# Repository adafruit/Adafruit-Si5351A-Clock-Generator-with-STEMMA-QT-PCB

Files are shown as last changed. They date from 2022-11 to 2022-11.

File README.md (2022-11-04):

## Adafruit Adafruit Si5351A Clock Generator with STEMMA QT 8KHz to 160MHz PCB

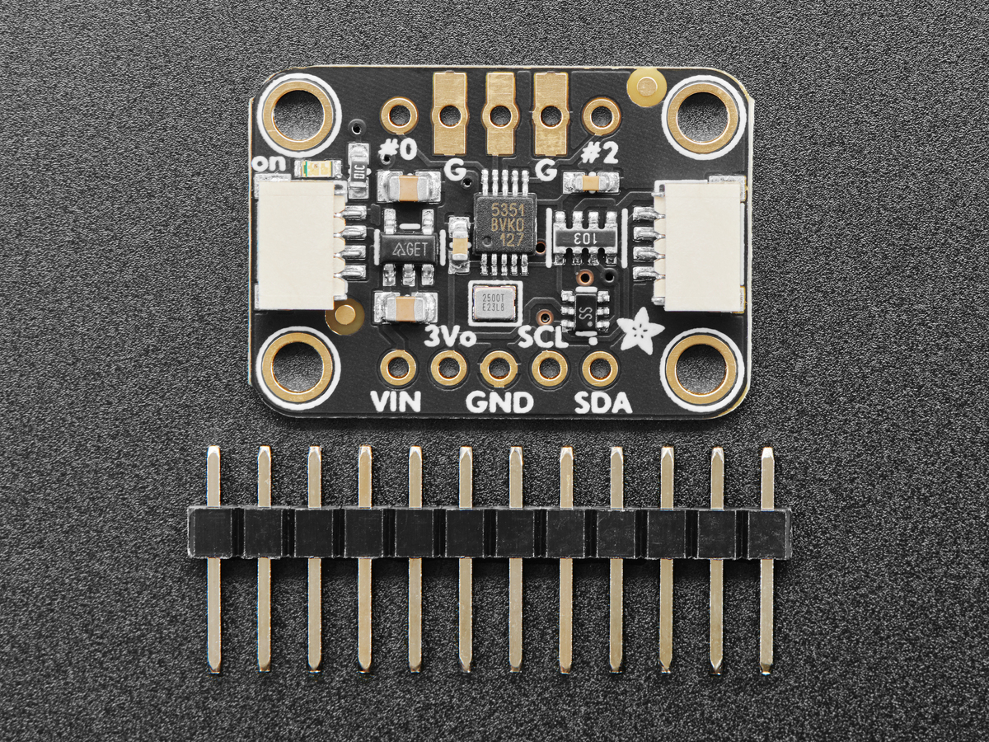
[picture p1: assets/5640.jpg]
<a href="http://www.adafruit.com/products/5640"><br/>
Click here to purchase one from the Adafruit shop</a>

PCB files for the Adafruit Adafruit Si5351A Clock Generator with STEMMA QT 8KHz to 160MHz. 

Format is EagleCAD schematic and board layout
* https://www.adafruit.com/product/5640

### Description

Never hunt around for another crystal again, with the Si5351A clock generator breakout from Adafruit! This chip has a precision 25MHz crystal reference and internal PLL and dividers so it can generate just about any frequency, from <8KHz up to 150+ MHz.

The Si5351A clock generator is an I2C controller clock generator. It uses the onboard precision clock to drive multiple PLL's and clock dividers using I2C instructions. By setting up the PLL and dividers you can create precise and arbitrary frequencies. There are three independent outputs, and each one can have a different frequency. Outputs are 3Vpp, either through a breadboard-friendly header or, for RF work, an optional edge-launch SMA connector for output #1. (If you need SMA-connector outputs for all three ports, check out the non-QT breakout here)

To get you going fast, we spun up a custom-made PCB in the STEMMA QT form factor, making it easy to interface with. The STEMMA QT connectors on either side are compatible with the SparkFun Qwiic I2C connectors. This allows you to make solderless connections between your development board and the Si5351 or to chain it with a wide range of other sensors and accessories using a compatible cable. Onboard 3.3V LDO and level shifters means its ready for use with 3V or 5V power and logic!

Best of all, we even have a great tutorial and library to get you started! Our code is designed for use with the Arduino-compatible microcontrollers and CircuitPython/Python using I2C support.

### License

Adafruit invests time and resources providing this open source design, please support Adafruit and open-source hardware by purchasing products from [Adafruit](https://www.adafruit.com)!

Designed by Limor Fried/Ladyada for Adafruit Industries.

Creative Commons Attribution/Share-Alike, all text above must be included in any redistribution. 
See license.txt for additional details.

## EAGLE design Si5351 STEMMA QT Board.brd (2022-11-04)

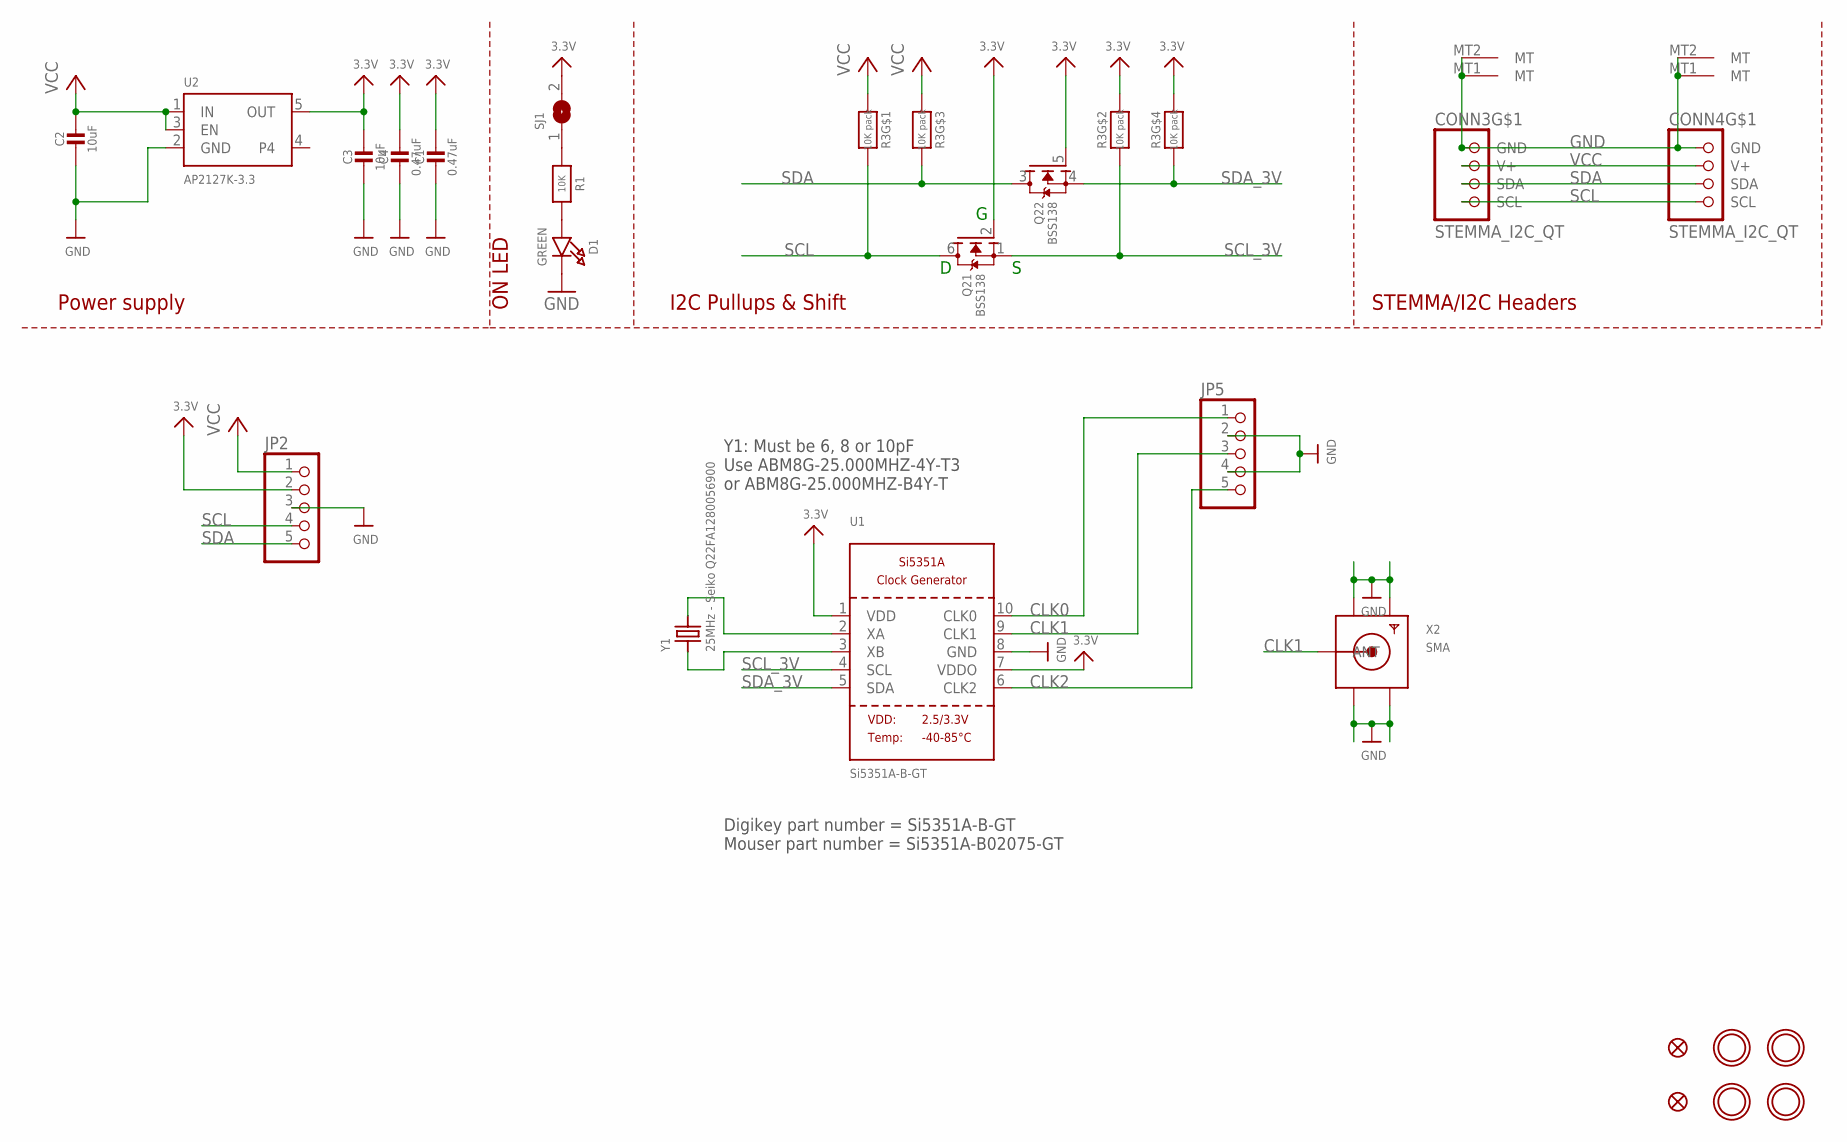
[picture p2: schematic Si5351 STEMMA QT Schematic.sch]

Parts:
C1, C4: 0.47uF; 0603-NO
C2, C3: 10uF; 0805-NO
CONN3, CONN4: STEMMA_I2C_QT; JST_SH4
D1: GREEN; CHIPLED_0603_NOOUTLINE
FID3, FID4: FIDUCIAL_1MM
JP2, JP5: HEADER-1X570MIL; 1X05_ROUND_70
Q2: BSS138; SOT363
R1: 10K; 0603-NO
R3: 10K pack; RESPACK_4X0603
SJ1: SOLDERJUMPERCLOSED; SOLDERJUMPER_CLOSEDWIRE
U1: Si5351A-B-GT; MSOP10
U2: AP2127K-3.3; SOT23-5
U$1, U$17, U$19, U$21: MOUNTINGHOLE2.5; MOUNTINGHOLE_2.5_PLATED
X2: SMA; SMA_EDGELAUNCH
Y1: 25MHz - Seiko Q22FA1280056900; CRYSTAL_2X1.6

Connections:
3.3V: C1.1, C3.1, C4.1, JP2.2, Q2.2 (G), Q2.5 (G), R3.2 (1), R3.4 (1), SJ1.2, U1.1 (VDD), U1.7 (VDDO), U2.5 (OUT)
CLK0: JP5.1, U1.10 (CLK0)
CLK1: JP5.3, U1.9 (CLK1), X2.P (ANT)
CLK2: JP5.5, U1.6 (CLK2)
GND: C1.2, C2.2, C3.2, C4.2, CONN3.1 (GND), CONN3.MT1 (MT), CONN3.MT2 (MT), CONN4.1 (GND), CONN4.MT1 (MT), CONN4.MT2 (MT), D1.C, JP2.3, JP5.2, JP5.4, U1.8 (GND), U2.2 (GND), X2.GND@1 (GND4), X2.GND@2 (GND3), X2.GND@3 (GND2), X2.GND@4 (GND1)
unnamed: D1.A, R1.2
unnamed: R1.1, SJ1.1
unnamed: U1.3 (XB), Y1.1
unnamed: U1.2 (XA), Y1.3 (2)
SCL: CONN3.4 (SCL), CONN4.4 (SCL), JP2.4, Q2.6 (D), R3.8 (2)
SCL_3V: Q2.1 (S), R3.7 (2), U1.4 (SCL)
SDA: CONN3.3 (SDA), CONN4.3 (SDA), JP2.5, Q2.3 (D), R3.6 (2)
SDA_3V: Q2.4 (S), R3.5 (2), U1.5 (SDA)
VCC: C2.1, CONN3.2 (V+), CONN4.2 (V+), JP2.1, R3.1, R3.3 (1), U2.1 (IN), U2.3 (EN)

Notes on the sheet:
I2C Pullups & Shift
STEMMA/I2C Headers
ON LED
Power supply
Digikey part number = Si5351A-B-GT Mouser part number = Si5351A-B02075-GT
Y1: Must be 6, 8 or 10pF Use ABM8G-25.000MHZ-4Y-T3 or ABM8G-25.000MHZ-B4Y-T

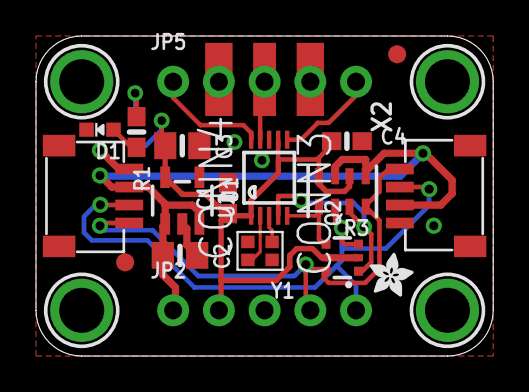
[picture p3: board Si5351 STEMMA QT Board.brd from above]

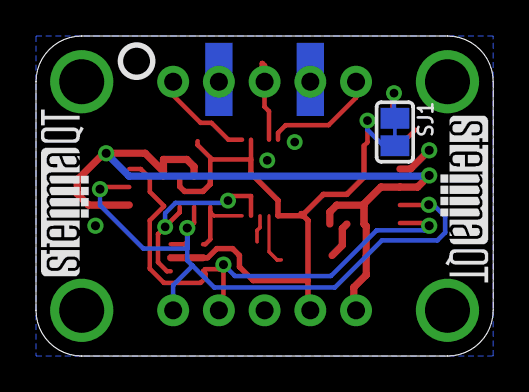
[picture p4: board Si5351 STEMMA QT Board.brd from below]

Board: 2 copper layers, 25.4 x 17.8 mm, 46 parts (13 on the bottom side), 14 nets.

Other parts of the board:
PLABEL0: PLABEL0
PLABEL1: PLABEL1
PLABEL2: PLABEL2
PLABEL3: PLABEL3
PLABEL4: PLABEL4
PLABEL5: PLABEL5
PLABEL6: PLABEL6
PLABEL7: PLABEL7
PLABEL8: PLABEL8
PLABEL9: PLABEL9
PLABEL10: PLABEL10
PLABEL11: PLABEL11
PLABEL12: PLABEL12
PLABEL13: PLABEL13
PLABEL14: PLABEL14
PLABEL15: PLABEL15
PLABEL16: PLABEL16
PLABEL17: PLABEL17
PLABEL18: PLABEL18
U$9: ADAFRUIT_2.5MM
U$25: PCBFEAT-REV-040
U$30, U$31: STEMMAQT

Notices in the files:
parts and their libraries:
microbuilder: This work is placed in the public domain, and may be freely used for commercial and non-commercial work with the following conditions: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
